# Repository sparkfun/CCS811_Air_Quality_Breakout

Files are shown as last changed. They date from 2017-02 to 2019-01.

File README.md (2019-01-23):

SparkFun CCS811 Air Quality Breakout
========================================

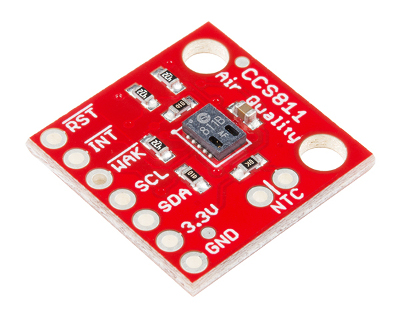
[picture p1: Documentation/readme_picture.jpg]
SparkFun CCS811 Breakout


[*SparkFun CCS811 (SEN-14193)*](https://www.sparkfun.com/products/14193)

The CCS811 is an digital gas sensor solution which integrates a metal oxide (MOX) gas sensor to detect a wide range of Volatile Organic Compounds (VOCs) for indoor air quality monitoring.

This product is designed to provide an easy hardware and software interface to the CCS811 sensor.

Repository Contents
-------------------

* **/Documentation** - Data sheets, additional product information
* **/Hardware** - Eagle design files (.brd, .sch)
* **/Production** - Production panel files (.brd)
* **/Software** - Python scripts for CCS811

Documentation
--------------
* **[Library](https://github.com/sparkfun/SparkFun_CCS811_Arduino_Library)** - Arduino library for the CCS811.
* **[Hookup Guide](https://learn.sparkfun.com/tutorials/ccs811-air-quality-breakout-hookup-guide)** - Basic hookup guide for the CCS811.
* **[SparkFun Fritzing repo](https://github.com/sparkfun/Fritzing_Parts)** - Fritzing diagrams for SparkFun products.
* **[SparkFun 3D Model repo](https://github.com/sparkfun/3D_Models)** - 3D models of SparkFun products. 

Product Versions
----------------
* [SEN-14193](https://www.sparkfun.com/)- CCS811 Breakout board

Version History
---------------
* [V 1.0.0](https://github.com/sparkfun/CCS811_Air_Quality_Breakout/tree/V_1.0.0) -- Initial commit of Arduino compatible library.

License Information
-------------------

This product is _**open source**_! 

Please review the LICENSE.md file for license information. 

If you have any questions or concerns on licensing, please contact techsupport@sparkfun.com.

Distributed as-is; no warranty is given.

- Your friends at SparkFun.

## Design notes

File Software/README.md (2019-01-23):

SparkFun <PRODUCT NAME> Software
=================================

Example software for use with <PRODUCT NAME>.

Possible examples include python scripts, bash scripts, SPICE simulations, etc. 

Python Example
==============

Python Example is tested on Raspberry Pi Zero W. It use *pigpio* library for i2c
 communication which is installed on the RPi by default. Before usage start the pigpio 
 library as a daemon.
 
 > sudo pigpiod
 
 Run example with

> python ccs811.py

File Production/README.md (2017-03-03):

SparkFun <PRODUCT NAME> Production Files
=========================================

These are the production files SparkFun uses for printing PCBs.

License Information
-------------------
This product is open source! 

The hardware is released under [Creative Commons ShareAlike 4.0 International](https://creativecommons.org/licenses/by-sa/4.0/).

Please use, reuse, and modify these files as you see fit. Please maintain attribution to SparkFun Electronics and release anything derivative under the same license.

Distributed as-is; no warranty is given.

- Your friends at SparkFun.

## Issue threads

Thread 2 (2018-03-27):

Python Example Returns Error

grapedrank, 2018-03-27:
Hey Guys,

had the sensor working for a few days and had python write values to mysql but now the device has thrown errors, if i remove the power and bring the sensor back up and run the example code it returns this

CO2:  0 ppm, TVOC:  0  temp:  25.0
ERROR!

and if i try run the code again i get this

Traceback (most recent call last):
  File "CCS811_example.py", line 6, in <module>
    ccs =  Adafruit_CCS811()
  File "/usr/local/lib/python2.7/dist-packages/Adafruit_CCS811/Adafruit_CCS811.py", line 92, in __init__
    raise Exception("Device returned an Error! Try removing and reapplying power to the device and running the code again.")
Exception: Device returned an Error! Try removing and reapplying power to the device and running the code again.

any ideas as to whats causing this?

nseidle, 2018-03-27:
It looks as though there is no comm with the sensor at all. Any chance you have a logic analyzer?

I would swap out sensors or controllers to isolate the problem.

Closed 2019-01-23.

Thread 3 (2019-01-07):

setEnvironmentalData after readAlgorithmResults?

supersjimmie, 2019-01-07:
In the example BME280Compensated.ino, it first does the ```readAlgorithmResults``` and then the ```setEnvironmentalData```. Are you sure that's the correct order? Shouldn't we first compensate/set and then read??

nseidle, 2019-01-23:
It's really not clear. The [CCS811 datasheet](https://cdn.sparkfun.com/datasheets/BreakoutBoards/CCS811_Programming_Guide.pdf) says:

> The CCS811 supports compensation for relative humidity and ambient temperature. The ENV_DATA registers can be updated with the temperature and humidity (TH) values on each cycle.

At what point in each cycle? It may not matter: the reading from the MOX sensor is going to change over many seconds and as the humidity and temperature change on similar, slow, whether the `setEnvironmentalData` comes before or after a `read` shouldn't effect the tVOC algorithm much. It will be corrected on the next read.

Closed 2019-01-23.

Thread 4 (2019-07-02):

Bad project description

trylika, 2019-07-02:
as stated in project description `CSS811 Air quality sensor capable of detecting CO2 and TVOCs`

should be `CCS811 Air quality sensor capable of detecting CO2 and TVOCs`

that is **C** not **S** :)

nseidle, 2019-07-14:
Nice catch! My eyes didn't see it even after you pointed it out. Fixed!

Closed 2019-07-14.

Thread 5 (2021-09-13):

Timing Issues Likely Related to Clock Holding

mnewman401, 2021-09-13:
I found a number of timing issues on the ESP8266 and ESP32 where the simple examples would not work with the CCS811. These are likely related to the fact that some I2C libraries (including the ESP32) do not support clock stretching. I have not verified that this is actually the reason for the failure.

In the existing libraries there was no error checking in the interactions with the device. There were a number of device interactions that did not always work. I added retries to work around this issue. I added error checking and perform retries on errors.

After a great deal of trial and error I was able to repair the library so it would work correctly on the SparkFun ESP32 Thing, the ESP32 Dev Module and my LOGGER ESP8266 board. The repaired code attached uses delays to make the interactions work. It should replace the existing modules cleanly. Error handling and retries are performed. Error reporting and some test code is included but turned off.

Also included is an enhanced simple test .INO that does a bit more reporting.  The library fixes are important this test is not.

[test.zip](https://github.com/sparkfun/CCS811_Air_Quality_Breakout/files/7157911/test.zip)

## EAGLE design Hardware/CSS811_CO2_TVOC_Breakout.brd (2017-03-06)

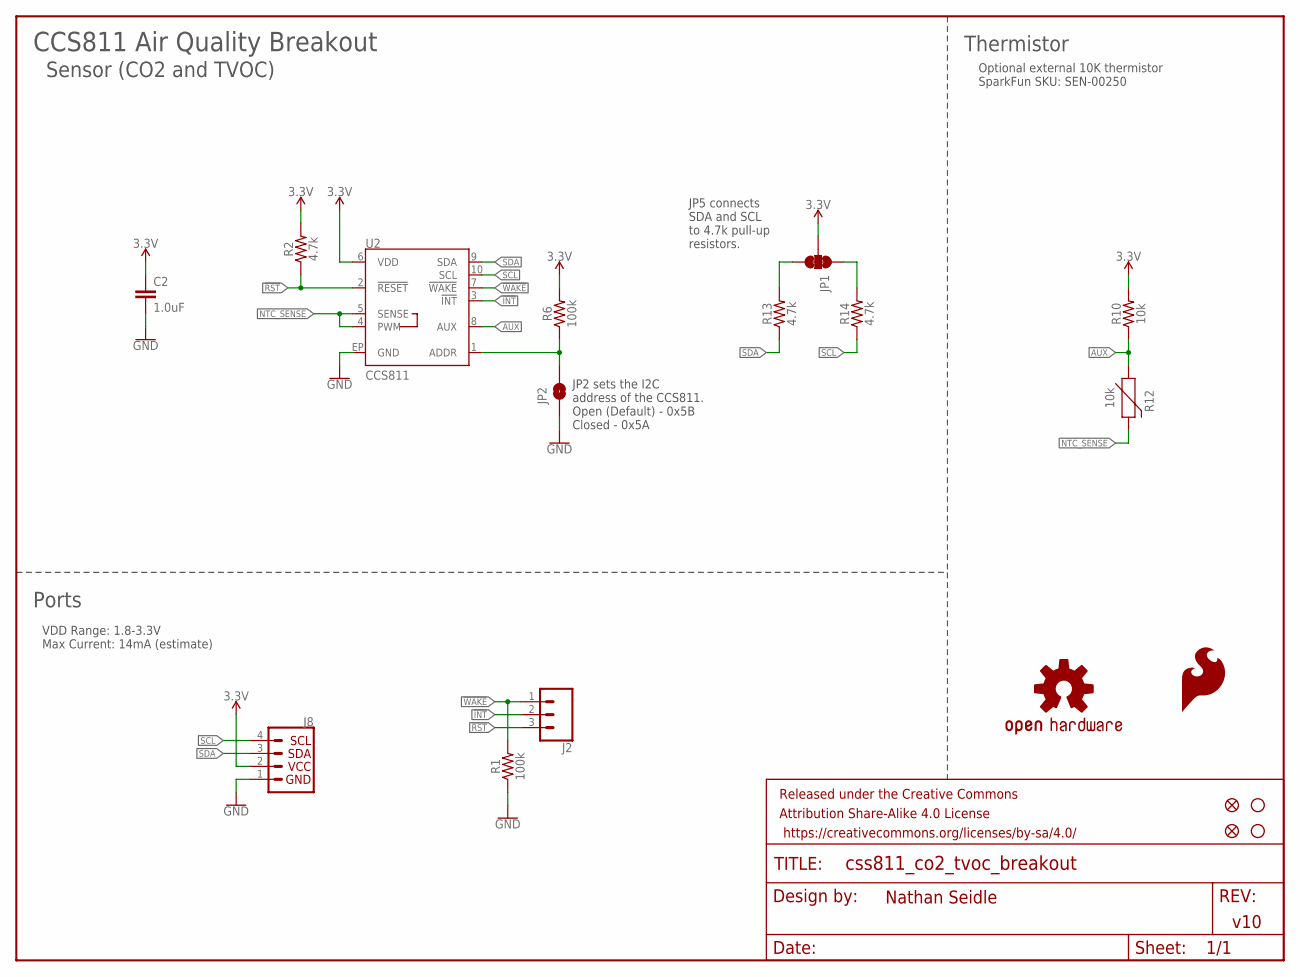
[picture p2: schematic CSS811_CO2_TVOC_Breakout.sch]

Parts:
C2: 1.0uF; 0603
FD1, FD2: FIDUCIAL1X2; FIDUCIAL-1X2
FRAME1: FRAME-LETTER; CREATIVE_COMMONS
H2, H4: STAND-OFF
J2: CONN_031X03_NO_SILK; 1X03_NO_SILK
J8: I2C_STANDARD_NO_SILK; 1X04_NO_SILK
JP1: JUMPER-SMT_3_2-NC_TRACE_SILK; SMT-JUMPER_3_2-NC_TRACE_SILK
JP2: JUMPER-SMT_2_NO_SILK; SMT-JUMPER_2_NO_SILK
LOGO1: SFE_LOGO_FLAME.2_INCH; SFE_LOGO_FLAME_.2
LOGO4: OSHW-LOGOS; OSHW-LOGO-S
R1, R6: 100k; 0603
R2, R13, R14: 4.7k; 0603
R10: 10k; 0603
R12: 10k; AXIAL-0.1
U2: CCS811; LGA10

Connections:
3.3V: C2.1, J8.2, JP1.2, R2.2, R6.2, R10.2, U2.6 (VDD)
!INT: J2.2, U2.3 (!INT!)
!RST: J2.3, R2.1, U2.2 (!RESET!)
!WAKE: J2.1, R1.2, U2.7 (!WAKE!)
AUX: R10.1, R12.P$1 (1), U2.8 (AUX)
CCS811_ADDR: JP2.2, R6.1, U2.1 (ADDR)
GND: C2.2, J8.1, JP2.1, R1.1, U2.EP (GND)
unnamed: JP1.3, R13.2
unnamed: JP1.1, R14.2
NTC_SENSE: R12.P$2 (2), U2.4 (PWM), U2.5 (SENSE)
SCL: J8.4, R14.1, U2.10 (SCL)
SDA: J8.3, R13.1, U2.9 (SDA)

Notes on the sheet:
VDD Range: 1.8-3.3V Max Current: 14mA (estimate)
CCS811 Air Quality Breakout
JP2 sets the I2C address of the CCS811. Open (Default) - 0x5B Closed - 0x5A
JP5 connects SDA and SCL to 4.7k pull-up resistors.
v10
Nathan Seidle
Optional external 10K thermistor SparkFun SKU: SEN-00250
Ports
Thermistor
Sensor (CO2 and TVOC)

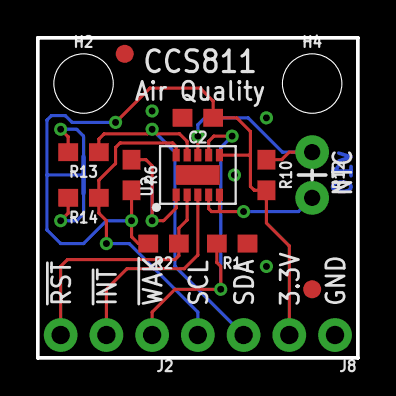
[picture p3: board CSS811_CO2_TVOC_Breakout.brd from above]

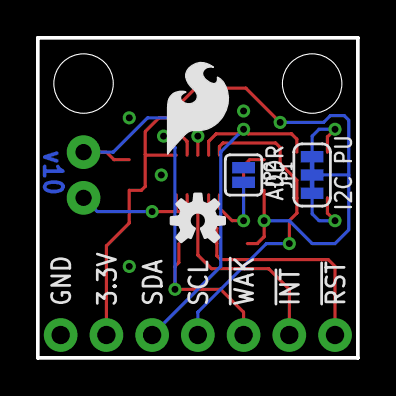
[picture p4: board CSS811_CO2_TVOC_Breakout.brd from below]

Board: 2 copper layers, 17.8 x 17.8 mm, 20 parts (4 on the bottom side), 12 nets.

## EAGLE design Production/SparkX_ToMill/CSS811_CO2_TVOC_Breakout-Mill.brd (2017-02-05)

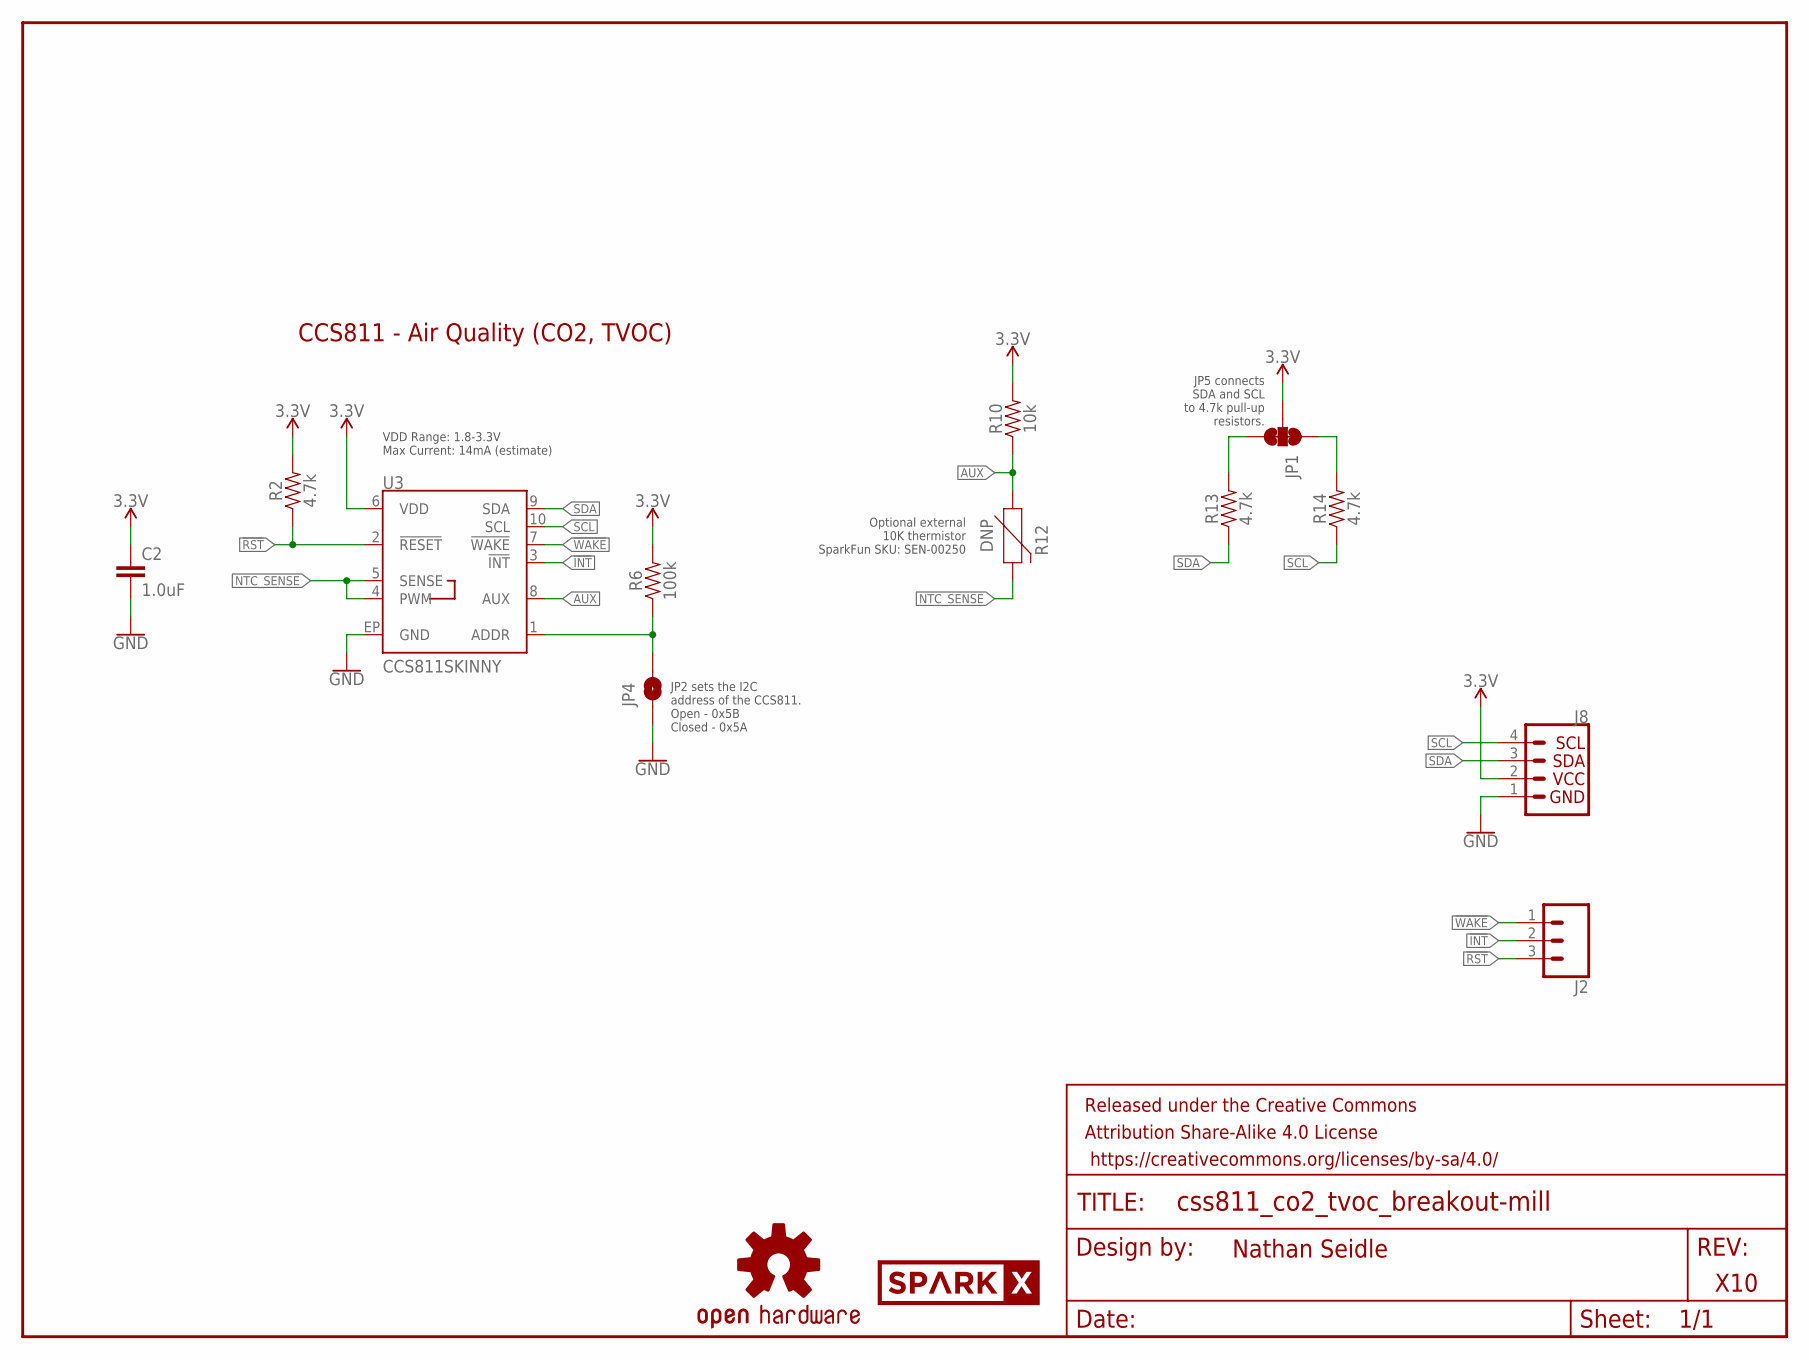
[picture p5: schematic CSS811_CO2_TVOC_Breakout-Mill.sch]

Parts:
C2: 1.0uF; 0603
FRAME1: FRAME-LETTER; CREATIVE_COMMONS
J2: CONN_031X03_NO_SILK; 1X03_NO_SILK
J8: I2C_STANDARD_NO_SILK; 1X04_NO_SILK
JP1: JUMPER-SMT_3_2-NC_TRACE_SILK; SMT-JUMPER_3_2-NC_TRACE_SILK
JP4: JUMPER-SMT_2_NO_SILK; SMT-JUMPER_2_NO_SILK
LOGO4: OSHW-LOGOS; OSHW-LOGO-S
R2, R13, R14: 4.7k; 0603
R6: 100k; 0603
R10: 10k; 0603
R12: DNP; AXIAL-0.1
U3: CCS811SKINNY; LGA10-MILLABLE
U$1: SPARKX-LOGO3; SPARKX-SMALL

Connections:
3.3V: C2.1, J8.2, JP1.2, R2.2, R6.2, R10.2, U3.6 (VDD)
!INT: J2.2, U3.3 (!INT!)
!RST: J2.3, R2.1, U3.2 (!RESET!)
!WAKE: J2.1, U3.7 (!WAKE!)
AUX: R10.1, R12.P$1 (1), U3.8 (AUX)
CCS811_ADDR: JP4.2, R6.1, U3.1 (ADDR)
GND: C2.2, J8.1, JP4.1, U3.EP (GND)
unnamed: JP1.3, R13.2
unnamed: JP1.1, R14.2
NTC_SENSE: R12.P$2 (2), U3.4 (PWM), U3.5 (SENSE)
SCL: J8.4, R14.1, U3.10 (SCL)
SDA: J8.3, R13.1, U3.9 (SDA)

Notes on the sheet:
VDD Range: 1.8-3.3V Max Current: 14mA (estimate)
CCS811 - Air Quality (CO2, TVOC)
JP2 sets the I2C address of the CCS811. Open - 0x5B Closed - 0x5A
JP5 connects SDA and SCL to 4.7k pull-up resistors.
X10
Nathan Seidle
Optional external 10K thermistor SparkFun SKU: SEN-00250

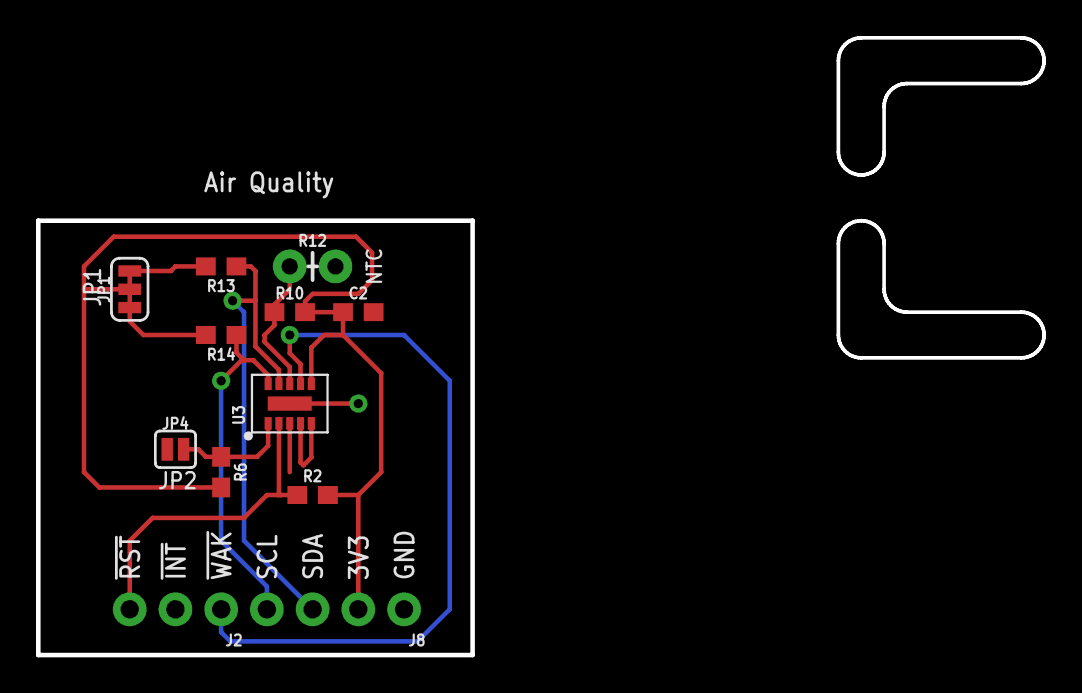
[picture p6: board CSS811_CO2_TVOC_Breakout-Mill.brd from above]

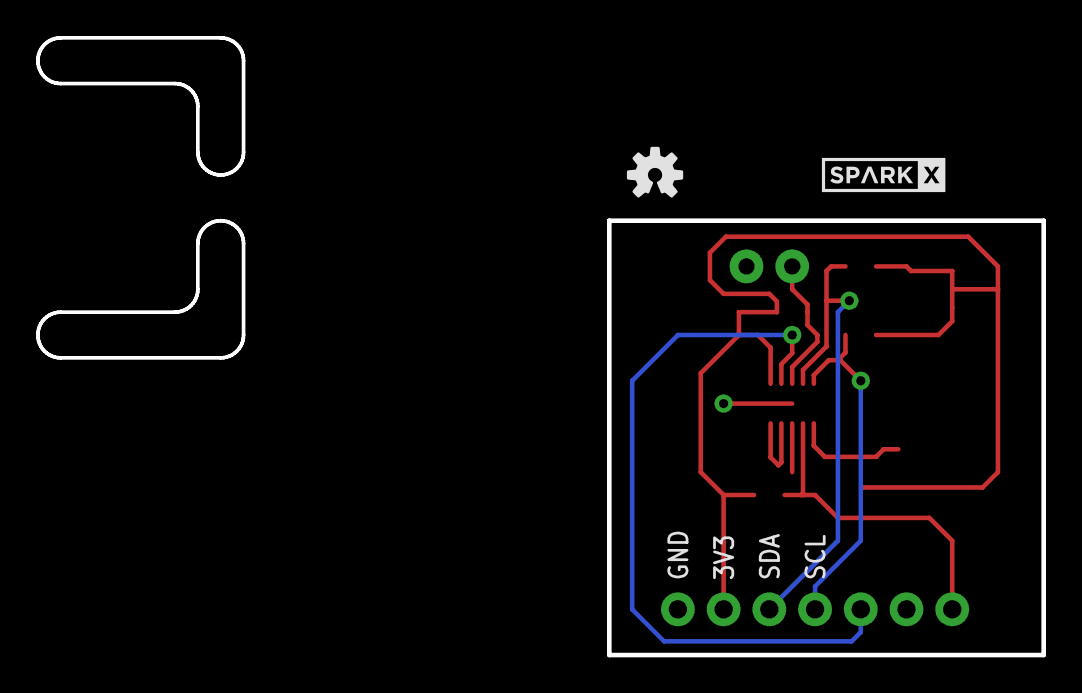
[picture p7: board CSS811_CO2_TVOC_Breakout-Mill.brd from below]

Board: 2 copper layers, 24.1 x 24.1 mm, 15 parts (2 on the bottom side), 12 nets.

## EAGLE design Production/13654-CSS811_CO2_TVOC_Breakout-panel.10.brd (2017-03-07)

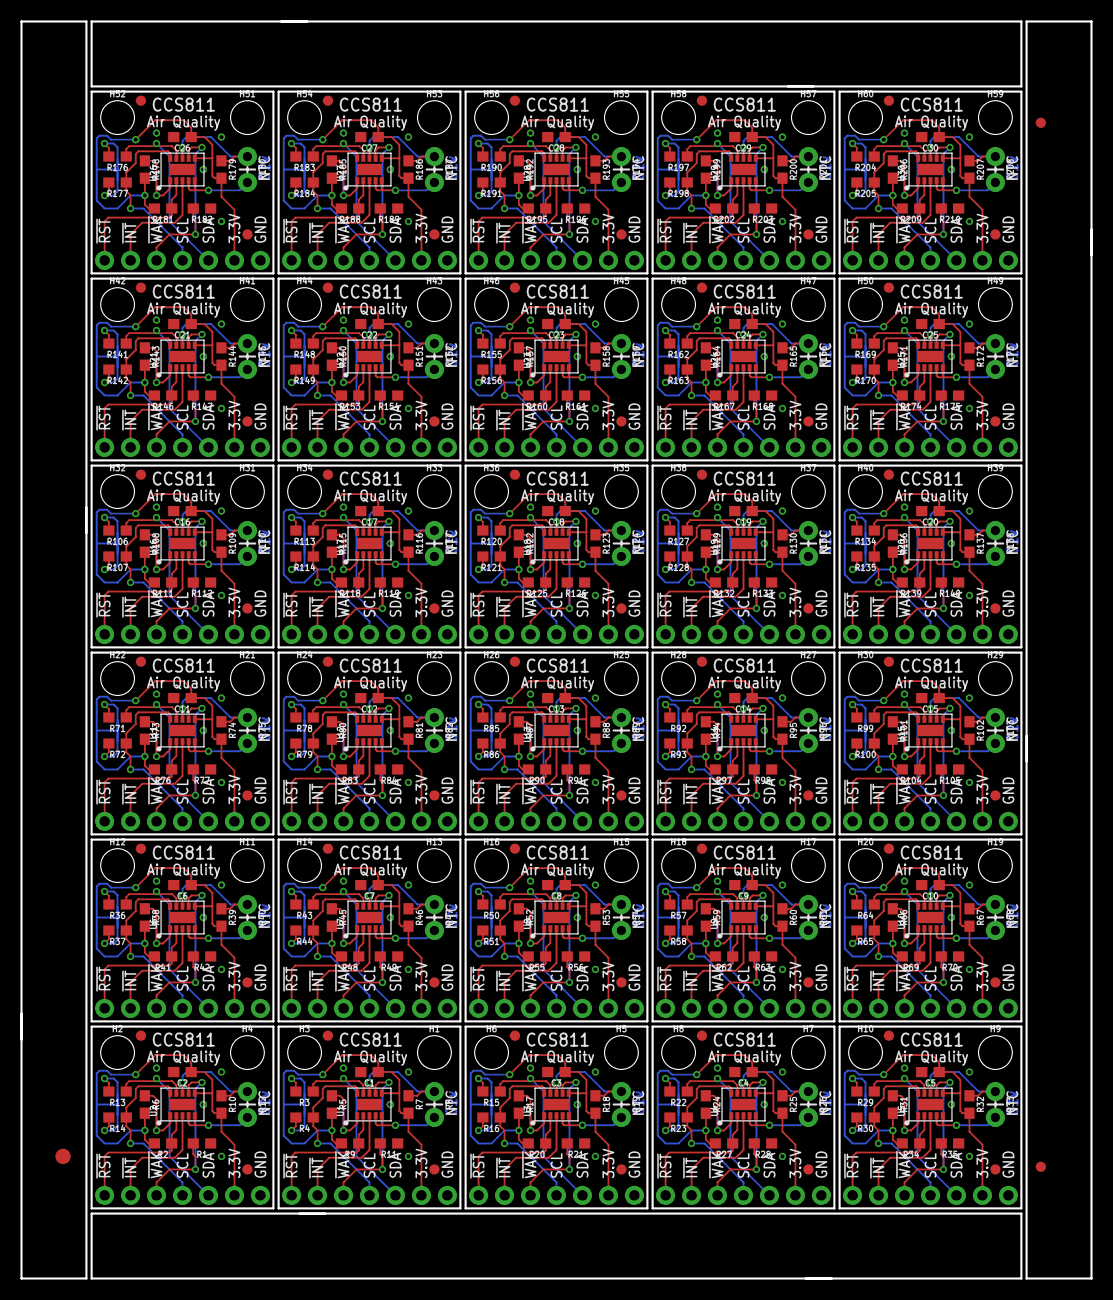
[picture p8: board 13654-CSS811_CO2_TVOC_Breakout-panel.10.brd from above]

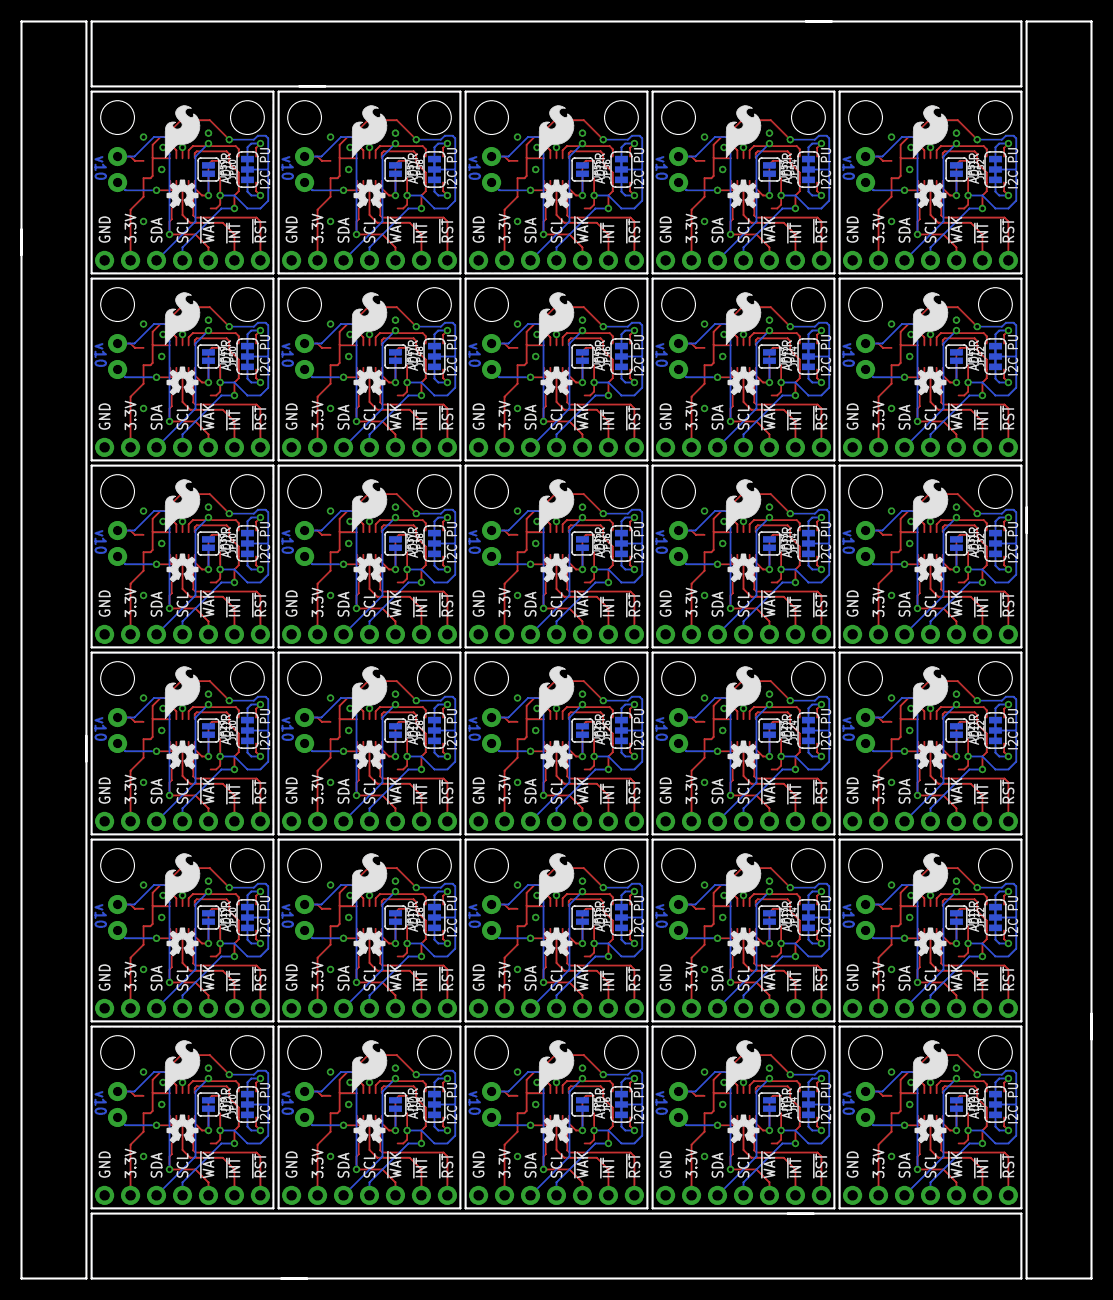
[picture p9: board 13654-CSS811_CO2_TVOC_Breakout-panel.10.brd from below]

Board: 2 copper layers, 104.6 x 122.9 mm, 573 parts (120 on the bottom side), 360 nets.

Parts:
C1, C2, C3, C4, C5, C6, C7, C8, C9, C10, C11, C12, C13, C14, C15, C16, C17, C18, C19, C20, C21, C22, C23, C24, C25, C26, C27, C28, C29, C30: 1.0uF; 0603
E$1: FIDUCIAL-1.5X3
E$7, E$8: FIDUCIAL-1X2
FD1, FD2, FD3, FD4, FD5, FD6, FD7, FD8, FD9, FD10, FD11, FD12, FD13, FD14, FD15, FD16, FD17, FD18, FD19, FD20, FD21, FD22, FD23, FD24, FD25, FD26, FD27, FD28, FD29, FD30, FD31, FD32, FD33, FD34, FD35, FD36, FD37, FD38, FD39, FD40, FD41, FD42, FD43, FD44, FD45, FD46, FD47, FD48, FD49, FD50, FD51, FD52, FD53, FD54, FD55, FD56, FD57, FD58, FD59, FD60: FIDUCIAL1X2; FIDUCIAL-1X2
H1, H2, H3, H4, H5, H6, H7, H8, H9, H10, H11, H12, H13, H14, H15, H16, H17, H18, H19, H20, H21, H22, H23, H24, H25, H26, H27, H28, H29, H30, H31, H32, H33, H34, H35, H36, H37, H38, H39, H40, H41, H42, H43, H44, H45, H46, H47, H48, H49, H50, H51, H52, H53, H54, H55, H56, H57, H58, H59, H60: STAND-OFF
J1, J4, J6, J8, J9, J11, J13, J15, J17, J19, J21, J23, J25, J27, J29, J31, J33, J35, J37, J39, J41, J43, J45, J47, J49, J51, J53, J55, J57, J59: 1X04_NO_SILK
J2, J3, J5, J7, J10, J12, J14, J16, J18, J20, J22, J24, J26, J28, J30, J32, J34, J36, J38, J40, J42, J44, J46, J48, J50, J52, J54, J56, J58, J60: 1X03_NO_SILK
JP1, JP4, JP6, JP8, JP10, JP12, JP14, JP16, JP18, JP20, JP22, JP24, JP26, JP28, JP30, JP32, JP34, JP36, JP38, JP40, JP42, JP44, JP46, JP48, JP50, JP52, JP54, JP56, JP58, JP60: SMT-JUMPER_3_2-NC_TRACE_SILK
JP2, JP3, JP5, JP7, JP9, JP11, JP13, JP15, JP17, JP19, JP21, JP23, JP25, JP27, JP29, JP31, JP33, JP35, JP37, JP39, JP41, JP43, JP45, JP47, JP49, JP51, JP53, JP55, JP57, JP59: SMT-JUMPER_2_NO_SILK
LOGO1, LOGO3, LOGO6, LOGO8, LOGO10, LOGO12, LOGO14, LOGO16, LOGO18, LOGO20, LOGO22, LOGO24, LOGO26, LOGO28, LOGO30, LOGO32, LOGO34, LOGO36, LOGO38, LOGO40, LOGO42, LOGO44, LOGO46, LOGO48, LOGO50, LOGO52, LOGO54, LOGO56, LOGO58, LOGO60: SFE_LOGO_FLAME.2_INCH; SFE_LOGO_FLAME_.2
LOGO2, LOGO4, LOGO5, LOGO7, LOGO9, LOGO11, LOGO13, LOGO15, LOGO17, LOGO19, LOGO21, LOGO23, LOGO25, LOGO27, LOGO29, LOGO31, LOGO33, LOGO35, LOGO37, LOGO39, LOGO41, LOGO43, LOGO45, LOGO47, LOGO49, LOGO51, LOGO53, LOGO55, LOGO57, LOGO59: OSHW-LOGOS; OSHW-LOGO-S
R1, R5, R6, R11, R17, R21, R24, R28, R31, R35, R38, R42, R45, R49, R52, R56, R59, R63, R66, R70, R73, R77, R80, R84, R87, R91, R94, R98, R101, R105, R108, R112, R115, R119, R122, R126, R129, R133, R136, R140, R143, R147, R150, R154, R157, R161, R164, R168, R171, R175, R178, R182, R185, R189, R192, R196, R199, R203, R206, R210: 100k; 0603
R2, R3, R4, R9, R13, R14, R15, R16, R20, R22, R23, R27, R29, R30, R34, R36, R37, R41, R43, R44, R48, R50, R51, R55, R57, R58, R62, R64, R65, R69, R71, R72, R76, R78, R79, R83, R85, R86, R90, R92, R93, R97, R99, R100, R104, R106, R107, R111, R113, R114, R118, R120, R121, R125, R127, R128, R132, R134, R135, R139, R141, R142, R146, R148, R149, R153, R155, R156, R160, R162, R163, R167, R169, R170, R174, R176, R177, R181, R183, R184, R188, R190, R191, R195, R197, R198, R202, R204, R205, R209: 4.7k; 0603
R7, R10, R18, R25, R32, R39, R46, R53, R60, R67, R74, R81, R88, R95, R102, R109, R116, R123, R130, R137, R144, R151, R158, R165, R172, R179, R186, R193, R200, R207: 10k; 0603
R8, R12, R19, R26, R33, R40, R47, R54, R61, R68, R75, R82, R89, R96, R103, R110, R117, R124, R131, R138, R145, R152, R159, R166, R173, R180, R187, R194, R201, R208: 10k; AXIAL-0.1
U1, U2, U3, U4, U5, U6, U7, U8, U9, U10, U11, U12, U13, U14, U15, U16, U17, U18, U19, U20, U21, U22, U23, U24, U25, U26, U27, U28, U29, U30: CCS811; LGA10

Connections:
3.3V: C2.1, J8.2, JP1.2, R2.2, R6.2, R10.2, U2.6
3.3V1: C1.1, J1.2, JP4.2, R5.2, R7.2, R9.2, U1.6
3.3V2: C3.1, J4.2, JP6.2, R17.2, R18.2, R20.2, U3.6
3.3V3: C4.1, J6.2, JP8.2, R24.2, R25.2, R27.2, U4.6
3.3V4: C5.1, J9.2, JP10.2, R31.2, R32.2, R34.2, U5.6
3.3V5: C6.1, J11.2, JP12.2, R38.2, R39.2, R41.2, U6.6
3.3V6: C7.1, J13.2, JP14.2, R45.2, R46.2, R48.2, U7.6
3.3V7: C8.1, J15.2, JP16.2, R52.2, R53.2, R55.2, U8.6
3.3V8: C9.1, J17.2, JP18.2, R59.2, R60.2, R62.2, U9.6
3.3V9: C10.1, J19.2, JP20.2, R66.2, R67.2, R69.2, U10.6
3.3V10: C11.1, J21.2, JP22.2, R73.2, R74.2, R76.2, U11.6
3.3V11: C12.1, J23.2, JP24.2, R80.2, R81.2, R83.2, U12.6
3.3V12: C13.1, J25.2, JP26.2, R87.2, R88.2, R90.2, U13.6
3.3V13: C14.1, J27.2, JP28.2, R94.2, R95.2, R97.2, U14.6
3.3V14: C15.1, J29.2, JP30.2, R101.2, R102.2, R104.2, U15.6
3.3V15: C16.1, J31.2, JP32.2, R108.2, R109.2, R111.2, U16.6
3.3V16: C17.1, J33.2, JP34.2, R115.2, R116.2, R118.2, U17.6
3.3V17: C18.1, J35.2, JP36.2, R122.2, R123.2, R125.2, U18.6
3.3V18: C19.1, J37.2, JP38.2, R129.2, R130.2, R132.2, U19.6
3.3V19: C20.1, J39.2, JP40.2, R136.2, R137.2, R139.2, U20.6
3.3V20: C21.1, J41.2, JP42.2, R143.2, R144.2, R146.2, U21.6
3.3V21: C22.1, J43.2, JP44.2, R150.2, R151.2, R153.2, U22.6
3.3V22: C23.1, J45.2, JP46.2, R157.2, R158.2, R160.2, U23.6
3.3V23: C24.1, J47.2, JP48.2, R164.2, R165.2, R167.2, U24.6
3.3V24: C25.1, J49.2, JP50.2, R171.2, R172.2, R174.2, U25.6
3.3V25: C26.1, J51.2, JP52.2, R178.2, R179.2, R181.2, U26.6
3.3V26: C27.1, J53.2, JP54.2, R185.2, R186.2, R188.2, U27.6
3.3V27: C28.1, J55.2, JP56.2, R192.2, R193.2, R195.2, U28.6
3.3V28: C29.1, J57.2, JP58.2, R199.2, R200.2, R202.2, U29.6
3.3V29: C30.1, J59.2, JP60.2, R206.2, R207.2, R209.2, U30.6
!INT: J2.2, U2.3
!INT1: J3.2, U1.3
!INT2: J5.2, U3.3
!INT3: J7.2, U4.3
!INT4: J10.2, U5.3
!INT5: J12.2, U6.3
!INT6: J14.2, U7.3
!INT7: J16.2, U8.3
!INT8: J18.2, U9.3
!INT9: J20.2, U10.3
!INT10: J22.2, U11.3
!INT11: J24.2, U12.3
!INT12: J26.2, U13.3
!INT13: J28.2, U14.3
!INT14: J30.2, U15.3
!INT15: J32.2, U16.3
!INT16: J34.2, U17.3
!INT17: J36.2, U18.3
!INT18: J38.2, U19.3
!INT19: J40.2, U20.3
!INT20: J42.2, U21.3
!INT21: J44.2, U22.3
!INT22: J46.2, U23.3
!INT23: J48.2, U24.3
!INT24: J50.2, U25.3
!INT25: J52.2, U26.3
!INT26: J54.2, U27.3
!INT27: J56.2, U28.3
!INT28: J58.2, U29.3
!INT29: J60.2, U30.3
!RST: J2.3, R2.1, U2.2
!RST1: J3.3, R9.1, U1.2
!RST2: J5.3, R20.1, U3.2
!RST3: J7.3, R27.1, U4.2
!RST4: J10.3, R34.1, U5.2
!RST5: J12.3, R41.1, U6.2
!RST6: J14.3, R48.1, U7.2
!RST7: J16.3, R55.1, U8.2
!RST8: J18.3, R62.1, U9.2
!RST9: J20.3, R69.1, U10.2
!RST10: J22.3, R76.1, U11.2
!RST11: J24.3, R83.1, U12.2
!RST12: J26.3, R90.1, U13.2
!RST13: J28.3, R97.1, U14.2
!RST14: J30.3, R104.1, U15.2
!RST15: J32.3, R111.1, U16.2
!RST16: J34.3, R118.1, U17.2
!RST17: J36.3, R125.1, U18.2
!RST18: J38.3, R132.1, U19.2
!RST19: J40.3, R139.1, U20.2
!RST20: J42.3, R146.1, U21.2
!RST21: J44.3, R153.1, U22.2
!RST22: J46.3, R160.1, U23.2
!RST23: J48.3, R167.1, U24.2
!RST24: J50.3, R174.1, U25.2
!RST25: J52.3, R181.1, U26.2
!RST26: J54.3, R188.1, U27.2
!RST27: J56.3, R195.1, U28.2
!RST28: J58.3, R202.1, U29.2
!RST29: J60.3, R209.1, U30.2
!WAKE: J2.1, R1.2, U2.7
!WAKE1: J3.1, R11.2, U1.7
!WAKE2: J5.1, R21.2, U3.7
!WAKE3: J7.1, R28.2, U4.7
!WAKE4: J10.1, R35.2, U5.7
!WAKE5: J12.1, R42.2, U6.7
!WAKE6: J14.1, R49.2, U7.7
!WAKE7: J16.1, R56.2, U8.7
!WAKE8: J18.1, R63.2, U9.7
!WAKE9: J20.1, R70.2, U10.7
!WAKE10: J22.1, R77.2, U11.7
!WAKE11: J24.1, R84.2, U12.7
!WAKE12: J26.1, R91.2, U13.7
!WAKE13: J28.1, R98.2, U14.7
!WAKE14: J30.1, R105.2, U15.7
!WAKE15: J32.1, R112.2, U16.7
!WAKE16: J34.1, R119.2, U17.7
!WAKE17: J36.1, R126.2, U18.7
!WAKE18: J38.1, R133.2, U19.7
!WAKE19: J40.1, R140.2, U20.7
!WAKE20: J42.1, R147.2, U21.7
!WAKE21: J44.1, R154.2, U22.7
!WAKE22: J46.1, R161.2, U23.7
!WAKE23: J48.1, R168.2, U24.7
!WAKE24: J50.1, R175.2, U25.7
!WAKE25: J52.1, R182.2, U26.7
!WAKE26: J54.1, R189.2, U27.7
!WAKE27: J56.1, R196.2, U28.7
!WAKE28: J58.1, R203.2, U29.7
!WAKE29: J60.1, R210.2, U30.7
AUX: R10.1, R12.P$1, U2.8
AUX1: R7.1, R8.P$1, U1.8
AUX2: R18.1, R19.P$1, U3.8
AUX3: R25.1, R26.P$1, U4.8
AUX4: R32.1, R33.P$1, U5.8
AUX5: R39.1, R40.P$1, U6.8
AUX6: R46.1, R47.P$1, U7.8
AUX7: R53.1, R54.P$1, U8.8
AUX8: R60.1, R61.P$1, U9.8
AUX9: R67.1, R68.P$1, U10.8
AUX10: R74.1, R75.P$1, U11.8
AUX11: R81.1, R82.P$1, U12.8
AUX12: R88.1, R89.P$1, U13.8
AUX13: R95.1, R96.P$1, U14.8
AUX14: R102.1, R103.P$1, U15.8
AUX15: R109.1, R110.P$1, U16.8
AUX16: R116.1, R117.P$1, U17.8
AUX17: R123.1, R124.P$1, U18.8
AUX18: R130.1, R131.P$1, U19.8
AUX19: R137.1, R138.P$1, U20.8
AUX20: R144.1, R145.P$1, U21.8
AUX21: R151.1, R152.P$1, U22.8
AUX22: R158.1, R159.P$1, U23.8
AUX23: R165.1, R166.P$1, U24.8
AUX24: R172.1, R173.P$1, U25.8
AUX25: R179.1, R180.P$1, U26.8
AUX26: R186.1, R187.P$1, U27.8
AUX27: R193.1, R194.P$1, U28.8
AUX28: R200.1, R201.P$1, U29.8
AUX29: R207.1, R208.P$1, U30.8
CCS811_ADDR: JP2.2, R6.1, U2.1
CCS811_ADDR1: JP3.2, R5.1, U1.1
CCS811_ADDR2: JP5.2, R17.1, U3.1
CCS811_ADDR3: JP7.2, R24.1, U4.1
CCS811_ADDR4: JP9.2, R31.1, U5.1
CCS811_ADDR5: JP11.2, R38.1, U6.1
CCS811_ADDR6: JP13.2, R45.1, U7.1
CCS811_ADDR7: JP15.2, R52.1, U8.1
CCS811_ADDR8: JP17.2, R59.1, U9.1
CCS811_ADDR9: JP19.2, R66.1, U10.1
CCS811_ADDR10: JP21.2, R73.1, U11.1
CCS811_ADDR11: JP23.2, R80.1, U12.1
CCS811_ADDR12: JP25.2, R87.1, U13.1
CCS811_ADDR13: JP27.2, R94.1, U14.1
CCS811_ADDR14: JP29.2, R101.1, U15.1
CCS811_ADDR15: JP31.2, R108.1, U16.1
CCS811_ADDR16: JP33.2, R115.1, U17.1
CCS811_ADDR17: JP35.2, R122.1, U18.1
CCS811_ADDR18: JP37.2, R129.1, U19.1
CCS811_ADDR19: JP39.2, R136.1, U20.1
CCS811_ADDR20: JP41.2, R143.1, U21.1
CCS811_ADDR21: JP43.2, R150.1, U22.1
CCS811_ADDR22: JP45.2, R157.1, U23.1
CCS811_ADDR23: JP47.2, R164.1, U24.1
CCS811_ADDR24: JP49.2, R171.1, U25.1
CCS811_ADDR25: JP51.2, R178.1, U26.1
CCS811_ADDR26: JP53.2, R185.1, U27.1
CCS811_ADDR27: JP55.2, R192.1, U28.1
CCS811_ADDR28: JP57.2, R199.1, U29.1
CCS811_ADDR29: JP59.2, R206.1, U30.1
GND: C2.2, J8.1, JP2.1, R1.1, U2.EP
GND1: C1.2, J1.1, JP3.1, R11.1, U1.EP
GND2: C3.2, J4.1, JP5.1, R21.1, U3.EP
GND3: C4.2, J6.1, JP7.1, R28.1, U4.EP
GND4: C5.2, J9.1, JP9.1, R35.1, U5.EP
GND5: C6.2, J11.1, JP11.1, R42.1, U6.EP
GND6: C7.2, J13.1, JP13.1, R49.1, U7.EP
GND7: C8.2, J15.1, JP15.1, R56.1, U8.EP
GND8: C9.2, J17.1, JP17.1, R63.1, U9.EP
GND9: C10.2, J19.1, JP19.1, R70.1, U10.EP
GND10: C11.2, J21.1, JP21.1, R77.1, U11.EP
GND11: C12.2, J23.1, JP23.1, R84.1, U12.EP
GND12: C13.2, J25.1, JP25.1, R91.1, U13.EP
GND13: C14.2, J27.1, JP27.1, R98.1, U14.EP
GND14: C15.2, J29.1, JP29.1, R105.1, U15.EP
GND15: C16.2, J31.1, JP31.1, R112.1, U16.EP
GND16: C17.2, J33.1, JP33.1, R119.1, U17.EP
GND17: C18.2, J35.1, JP35.1, R126.1, U18.EP
GND18: C19.2, J37.1, JP37.1, R133.1, U19.EP
GND19: C20.2, J39.1, JP39.1, R140.1, U20.EP
GND20: C21.2, J41.1, JP41.1, R147.1, U21.EP
GND21: C22.2, J43.1, JP43.1, R154.1, U22.EP
GND22: C23.2, J45.1, JP45.1, R161.1, U23.EP
GND23: C24.2, J47.1, JP47.1, R168.1, U24.EP
GND24: C25.2, J49.1, JP49.1, R175.1, U25.EP
GND25: C26.2, J51.1, JP51.1, R182.1, U26.EP
GND26: C27.2, J53.1, JP53.1, R189.1, U27.EP
GND27: C28.2, J55.1, JP55.1, R196.1, U28.EP
GND28: C29.2, J57.1, JP57.1, R203.1, U29.EP
GND29: C30.2, J59.1, JP59.1, R210.1, U30.EP
unnamed: JP4.3, R3.2
unnamed: JP4.1, R4.2
unnamed: JP6.3, R15.2
unnamed: JP1.3, R13.2
unnamed: JP1.1, R14.2
unnamed: JP6.1, R16.2
unnamed: JP8.3, R22.2
unnamed: JP8.1, R23.2
unnamed: JP10.3, R29.2
unnamed: JP10.1, R30.2
unnamed: JP12.3, R36.2
unnamed: JP12.1, R37.2
unnamed: JP14.3, R43.2
unnamed: JP14.1, R44.2
unnamed: JP16.3, R50.2
unnamed: JP16.1, R51.2
unnamed: JP18.3, R57.2
unnamed: JP18.1, R58.2
unnamed: JP20.3, R64.2
unnamed: JP20.1, R65.2
unnamed: JP22.3, R71.2
unnamed: JP22.1, R72.2
unnamed: JP24.3, R78.2
unnamed: JP24.1, R79.2
unnamed: JP26.3, R85.2
unnamed: JP26.1, R86.2
unnamed: JP28.3, R92.2
unnamed: JP28.1, R93.2
unnamed: JP30.3, R99.2
unnamed: JP30.1, R100.2
unnamed: JP32.3, R106.2
unnamed: JP32.1, R107.2
unnamed: JP34.3, R113.2
unnamed: JP34.1, R114.2
unnamed: JP36.3, R120.2
unnamed: JP36.1, R121.2
unnamed: JP38.3, R127.2
unnamed: JP38.1, R128.2
unnamed: JP40.3, R134.2
unnamed: JP40.1, R135.2
unnamed: JP42.3, R141.2
unnamed: JP42.1, R142.2
unnamed: JP44.3, R148.2
unnamed: JP44.1, R149.2
unnamed: JP46.3, R155.2
unnamed: JP46.1, R156.2
unnamed: JP48.3, R162.2
unnamed: JP48.1, R163.2
unnamed: JP50.3, R169.2
unnamed: JP50.1, R170.2
unnamed: JP52.3, R176.2
unnamed: JP52.1, R177.2
unnamed: JP54.3, R183.2
unnamed: JP54.1, R184.2
unnamed: JP56.3, R190.2
unnamed: JP56.1, R191.2
unnamed: JP58.3, R197.2
unnamed: JP58.1, R198.2
unnamed: JP60.3, R204.2
unnamed: JP60.1, R205.2
NTC_SENSE: R12.P$2, U2.4, U2.5
NTC_SENSE1: R8.P$2, U1.4, U1.5
NTC_SENSE2: R19.P$2, U3.4, U3.5
NTC_SENSE3: R26.P$2, U4.4, U4.5
NTC_SENSE4: R33.P$2, U5.4, U5.5
NTC_SENSE5: R40.P$2, U6.4, U6.5
NTC_SENSE6: R47.P$2, U7.4, U7.5
NTC_SENSE7: R54.P$2, U8.4, U8.5
NTC_SENSE8: R61.P$2, U9.4, U9.5
NTC_SENSE9: R68.P$2, U10.4, U10.5
NTC_SENSE10: R75.P$2, U11.4, U11.5
NTC_SENSE11: R82.P$2, U12.4, U12.5
NTC_SENSE12: R89.P$2, U13.4, U13.5
NTC_SENSE13: R96.P$2, U14.4, U14.5
NTC_SENSE14: R103.P$2, U15.4, U15.5
NTC_SENSE15: R110.P$2, U16.4, U16.5
NTC_SENSE16: R117.P$2, U17.4, U17.5
NTC_SENSE17: R124.P$2, U18.4, U18.5
NTC_SENSE18: R131.P$2, U19.4, U19.5
NTC_SENSE19: R138.P$2, U20.4, U20.5
NTC_SENSE20: R145.P$2, U21.4, U21.5
NTC_SENSE21: R152.P$2, U22.4, U22.5
NTC_SENSE22: R159.P$2, U23.4, U23.5
NTC_SENSE23: R166.P$2, U24.4, U24.5
NTC_SENSE24: R173.P$2, U25.4, U25.5
NTC_SENSE25: R180.P$2, U26.4, U26.5
NTC_SENSE26: R187.P$2, U27.4, U27.5
NTC_SENSE27: R194.P$2, U28.4, U28.5
NTC_SENSE28: R201.P$2, U29.4, U29.5
NTC_SENSE29: R208.P$2, U30.4, U30.5
SCL: J8.4, R14.1, U2.10
SCL1: J1.4, R4.1, U1.10
SCL2: J4.4, R16.1, U3.10
SCL3: J6.4, R23.1, U4.10
SCL4: J9.4, R30.1, U5.10
SCL5: J11.4, R37.1, U6.10
SCL6: J13.4, R44.1, U7.10
SCL7: J15.4, R51.1, U8.10
SCL8: J17.4, R58.1, U9.10
SCL9: J19.4, R65.1, U10.10
SCL10: J21.4, R72.1, U11.10
SCL11: J23.4, R79.1, U12.10
SCL12: J25.4, R86.1, U13.10
SCL13: J27.4, R93.1, U14.10
SCL14: J29.4, R100.1, U15.10
SCL15: J31.4, R107.1, U16.10
SCL16: J33.4, R114.1, U17.10
SCL17: J35.4, R121.1, U18.10
SCL18: J37.4, R128.1, U19.10
SCL19: J39.4, R135.1, U20.10
SCL20: J41.4, R142.1, U21.10
SCL21: J43.4, R149.1, U22.10
SCL22: J45.4, R156.1, U23.10
SCL23: J47.4, R163.1, U24.10
SCL24: J49.4, R170.1, U25.10
SCL25: J51.4, R177.1, U26.10
SCL26: J53.4, R184.1, U27.10
SCL27: J55.4, R191.1, U28.10
SCL28: J57.4, R198.1, U29.10
SCL29: J59.4, R205.1, U30.10
SDA: J8.3, R13.1, U2.9
SDA1: J1.3, R3.1, U1.9
SDA2: J4.3, R15.1, U3.9
SDA3: J6.3, R22.1, U4.9
SDA4: J9.3, R29.1, U5.9
SDA5: J11.3, R36.1, U6.9
SDA6: J13.3, R43.1, U7.9
SDA7: J15.3, R50.1, U8.9
SDA8: J17.3, R57.1, U9.9
SDA9: J19.3, R64.1, U10.9
SDA10: J21.3, R71.1, U11.9
SDA11: J23.3, R78.1, U12.9
SDA12: J25.3, R85.1, U13.9
SDA13: J27.3, R92.1, U14.9
SDA14: J29.3, R99.1, U15.9
SDA15: J31.3, R106.1, U16.9
SDA16: J33.3, R113.1, U17.9
SDA17: J35.3, R120.1, U18.9
SDA18: J37.3, R127.1, U19.9
SDA19: J39.3, R134.1, U20.9
SDA20: J41.3, R141.1, U21.9
SDA21: J43.3, R148.1, U22.9
SDA22: J45.3, R155.1, U23.9
SDA23: J47.3, R162.1, U24.9
SDA24: J49.3, R169.1, U25.9
SDA25: J51.3, R176.1, U26.9
SDA26: J53.3, R183.1, U27.9
SDA27: J55.3, R190.1, U28.9
SDA28: J57.3, R197.1, U29.9
SDA29: J59.3, R204.1, U30.9

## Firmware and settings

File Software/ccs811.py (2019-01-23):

"""
CCS811 Air Quality Sensor Example Code
Author: Sasa Saftic (sasa@infincube.si)
infincube d.o.o.
Date: June 8th, 2017
License: This code is public domain

Based on Sparkfuns Example code written by Nathan Seidle

Read the TVOC and CO2 values from the SparkFun CSS811 breakout board

A new sensor requires at 48-burn in. Once burned in a sensor requires
20 minutes of run in before readings are considered good.

Tested on Raspberry Pi Zero W
"""

import pigpio
import time

CCS811_ADDR = 0x5B  # default I2C Address

CSS811_STATUS = 0x00
CSS811_MEAS_MODE = 0x01
CSS811_ALG_RESULT_DATA = 0x02
CSS811_RAW_DATA = 0x03
CSS811_ENV_DATA = 0x05
CSS811_NTC = 0x06
CSS811_THRESHOLDS = 0x10
CSS811_BASELINE = 0x11
CSS811_HW_ID = 0x20
CSS811_HW_VERSION = 0x21
CSS811_FW_BOOT_VERSION = 0x23
CSS811_FW_APP_VERSION = 0x24
CSS811_ERROR_ID = 0xE0
CSS811_APP_START = 0xF4
CSS811_SW_RESET = 0xFF


class CCS811:
    def __init__(self):
        self.pi = pigpio.pi()
        self.device = self.pi.i2c_open(1, 0x5B)
        self.tVOC = 0
        self.CO2 = 0

    def print_error(self):
        error = self.pi.i2c_read_byte_data(self.device, CSS811_ERROR_ID)
        message = 'Error: '

        if error & 1 << 5:
            message += 'HeaterSupply '
        elif error & 1 << 4:
            message += 'HeaterFault '
        elif error & 1 << 3:
            message += 'MaxResistance '
        elif error & 1 << 2:
            message += 'MeasModeInvalid '
        elif error & 1 << 1:
            message += 'ReadRegInvalid '
        elif error & 1 << 0:
            message += 'MsgInvalid '

        print(message)

    def check_for_error(self):
        value = self.pi.i2c_read_byte_data(self.device, CSS811_STATUS)
        return value & 1 << 0

    def app_valid(self):
        value = self.pi.i2c_read_byte_data(self.device, CSS811_STATUS)
        return value & 1 << 4

    def set_drive_mode(self, mode):
        if mode > 4:
            mode = 4

        setting = self.pi.i2c_read_byte_data(self.device, CSS811_MEAS_MODE)
        setting &= ~(0b00000111 << 4)
        setting |= (mode << 4)
        self.pi.i2c_write_byte_data(self.device, CSS811_MEAS_MODE, setting)

    def configure_ccs811(self):
        hardware_id = self.pi.i2c_read_byte_data(self.device, CSS811_HW_ID)

        if hardware_id != 0x81:
            raise ValueError('CCS811 not found. Please check wiring.')

        if self.check_for_error():
            self.print_error()
            raise ValueError('Error at Startup.')

        if not self.app_valid():
            raise ValueError('Error: App not valid.')

        self.pi.i2c_write_byte(self.device, CSS811_APP_START)

        if self.check_for_error():
            self.print_error()
            raise ValueError('Error at AppStart.')

        self.set_drive_mode(1)

        if self.check_for_error():
            self.print_error()
            raise ValueError('Error at setDriveMode.')

    def setup(self):
        print('Starting CCS811 Read')
        self.configure_ccs811()
        
        result = self.get_base_line()

        print("baseline for this sensor: 0x")
        if result < 0x100:
            print('0')
        if result < 0x10:
            print('0')
        print(result)

    def get_base_line(self):
        a, b = self.pi.i2c_read_i2c_block_data(self.device, CSS811_BASELINE, 2)
        baselineMSB = b[0]
        baselineLSB = b[1]
        baseline = (baselineMSB << 8) | baselineLSB
        return baseline

    def data_available(self):
        value = self.pi.i2c_read_byte_data(self.device, CSS811_STATUS)
        return value & 1 << 3

    def run(self):

        self.setup()

        while True:
            if self.data_available():
                self.read_logorithm_results()

                print("CO2[%d] tVOC[%d]" % (self.CO2, self.tVOC))

            elif self.check_for_error():
                self.print_error()

            time.sleep(1)

    def read_logorithm_results(self):
        b, d = self.pi.i2c_read_i2c_block_data(self.device, CSS811_ALG_RESULT_DATA, 4)

        co2MSB = d[0]
        co2LSB = d[1]
        tvocMSB = d[2]
        tvocLSB = d[3]

        self.CO2 = (co2MSB << 8) | co2LSB
        self.tVOC = (tvocMSB << 8) | tvocLSB


c = CCS811()
c.run()

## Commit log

2017-02-08 Adding panel and removing extraneous files.
    [CSS811_CO2_TVOC_Breakout.GBL, CSS811_CO2_TVOC_Breakout.GBO, CSS811_CO2_TVOC_Breakout.GBS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]
2017-02-08 Adding panel
    [CCS811-Panel.GBL, CCS811-Panel.GBO, CCS811-Panel.GBS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]
2017-02-08 Reviewed and fixed Panel
    [CCS811-Panel.brd, CSS811_CO2_TVOC_Breakout.brd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]
2017-02-09 Fixed Gerber .zip file
2017-02-13 Removing extra layers on layout
    [CSS811_CO2_TVOC_Breakout.brd]
2017-02-15 Added tight panel for ALLPCB
    [CCS811_Panel_ALLPCB.GBL, CCS811_Panel_ALLPCB.GBO, CCS811_Panel_ALLPCB.GBS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]
2017-02-15 Removing WAKE pin control to make examples simplier
    [CSS811_CO2_TVOC_Breakout.brd, CSS811_CO2_TVOC_Breakout.sch]
2017-03-03 Restructed github to match standards
    [CCS811-Panel.GBL, CCS811-Panel.GBO, CCS811-Panel.GBS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]
2017-03-03 Added temp library of new parts, added proper gitignore/gitattributes, switched sparkfun logo in for sparkx logo, cleaned up schematic, changed version number to v10
    [CSS811_CO2_TVOC_Breakout (2).brd, CSS811_CO2_TVOC_Breakout.brd, CSS811_CO2_TVOC_Breakout.sch]
2017-03-06 Updated to take care of checklist and review items
    [CSS811_CO2_TVOC_Breakout.brd, CSS811_CO2_TVOC_Breakout.sch]
2017-04-27 Squashed 'Libraries/Arduino/' content from commit edd7744
    git-subtree-dir: Libraries/Arduino
    git-subtree-split: edd774432433c4d31eca30ce538e26dbf3343691
2019-01-23 Removing library and firmware from repo. See SparkFun CCS811 Arduino Library for the latest.
    Library: https://github.com/sparkfun/SparkFun_CCS811_Arduino_Library
    [CSS811_CO2_TVOC_Breakout (2).brd, CSS811_CO2_TVOC_Breakout.brd]

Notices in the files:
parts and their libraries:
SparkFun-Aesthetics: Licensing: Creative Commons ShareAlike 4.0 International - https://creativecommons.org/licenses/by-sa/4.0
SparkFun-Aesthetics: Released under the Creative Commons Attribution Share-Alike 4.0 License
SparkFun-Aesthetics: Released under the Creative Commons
